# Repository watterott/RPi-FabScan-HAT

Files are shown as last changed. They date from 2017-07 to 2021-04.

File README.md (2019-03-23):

# RPi-FabScan-HAT
Raspberry Pi HAT (Hardware Attached on Top) to drive Stepper and Servo Motors or to build a 3D Laser Scanner.

Infos about the FabScan 3D-Scanner: http://www.fabscan.org

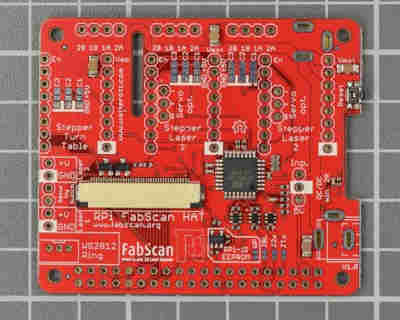
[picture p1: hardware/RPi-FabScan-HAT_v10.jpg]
RPi-FabScan-HAT


* Microchip ATmega328P with Arduino compatible Bootloader (optiboot)
* Sockets for Stepper Motor Drivers like StepStick or SilenStepStick
* Connectors for Servo Motors
* Laser control outputs
* [Raspberry Pi HAT](https://github.com/raspberrypi/hats) compatible (40 pin connector)
* Open-Source and released under the [Creative Commons Attribution Share-Alike License](https://creativecommons.org/licenses/by-sa/4.0/).
* **[Documentation on learn.watterott.com](https://learn.watterott.com)**

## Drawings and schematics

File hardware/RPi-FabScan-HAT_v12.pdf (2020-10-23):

## M1_EN

## M1_STEP

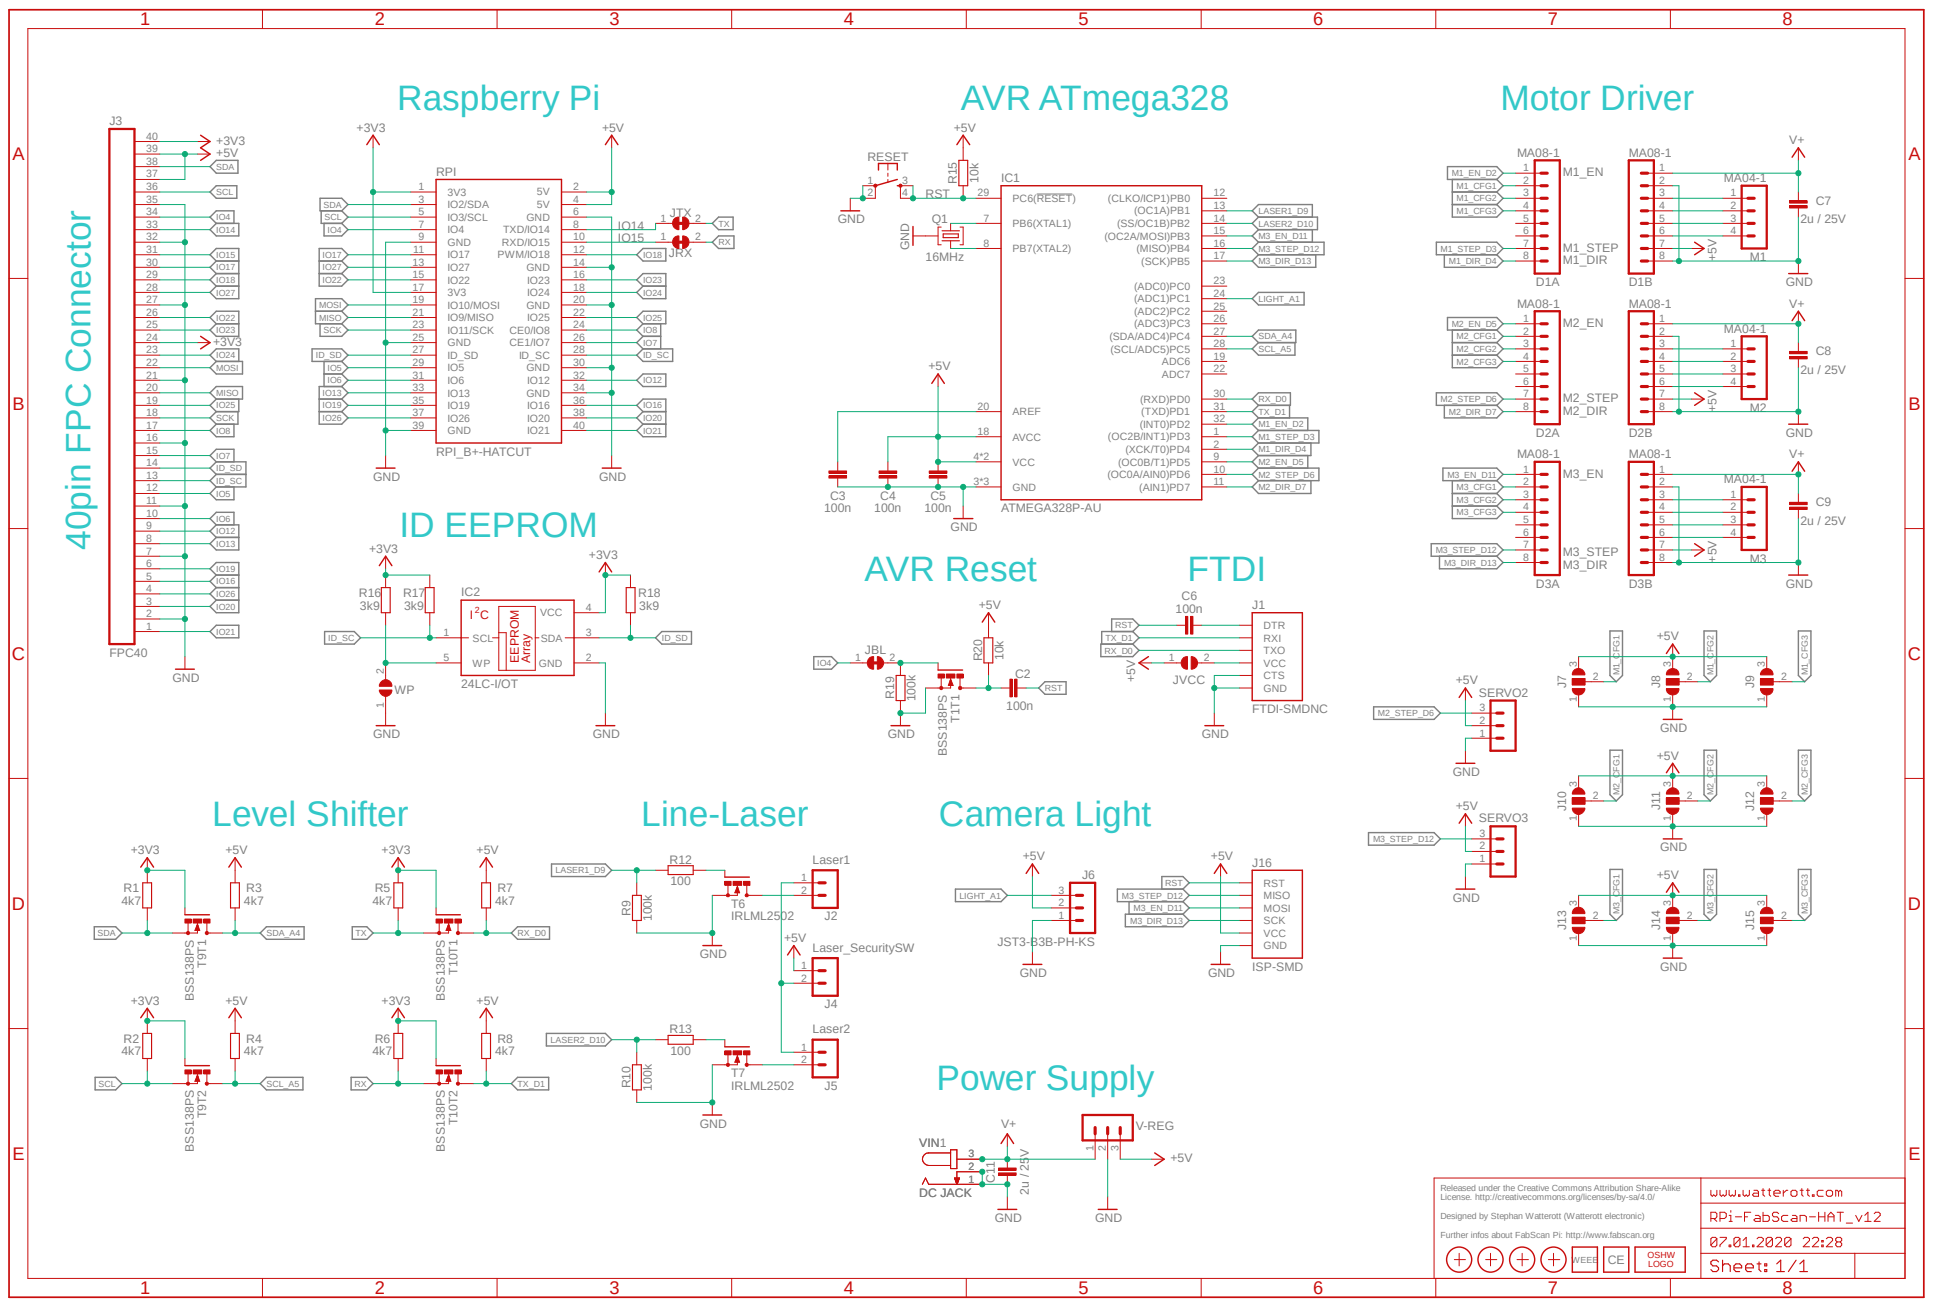
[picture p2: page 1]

M2_STEP_D6 +5V | 2

M3_STEP_D12 | 2

Released under the Creative Commons Attribution Share-Alike
License. http://creativecommons.org/licenses/by-sa/4.0/

Designed by Stephan Watterott (Watterott electronic)

Further infos about FabScan Pi: http://www.fabscan.org

# Vmot

# Vmot

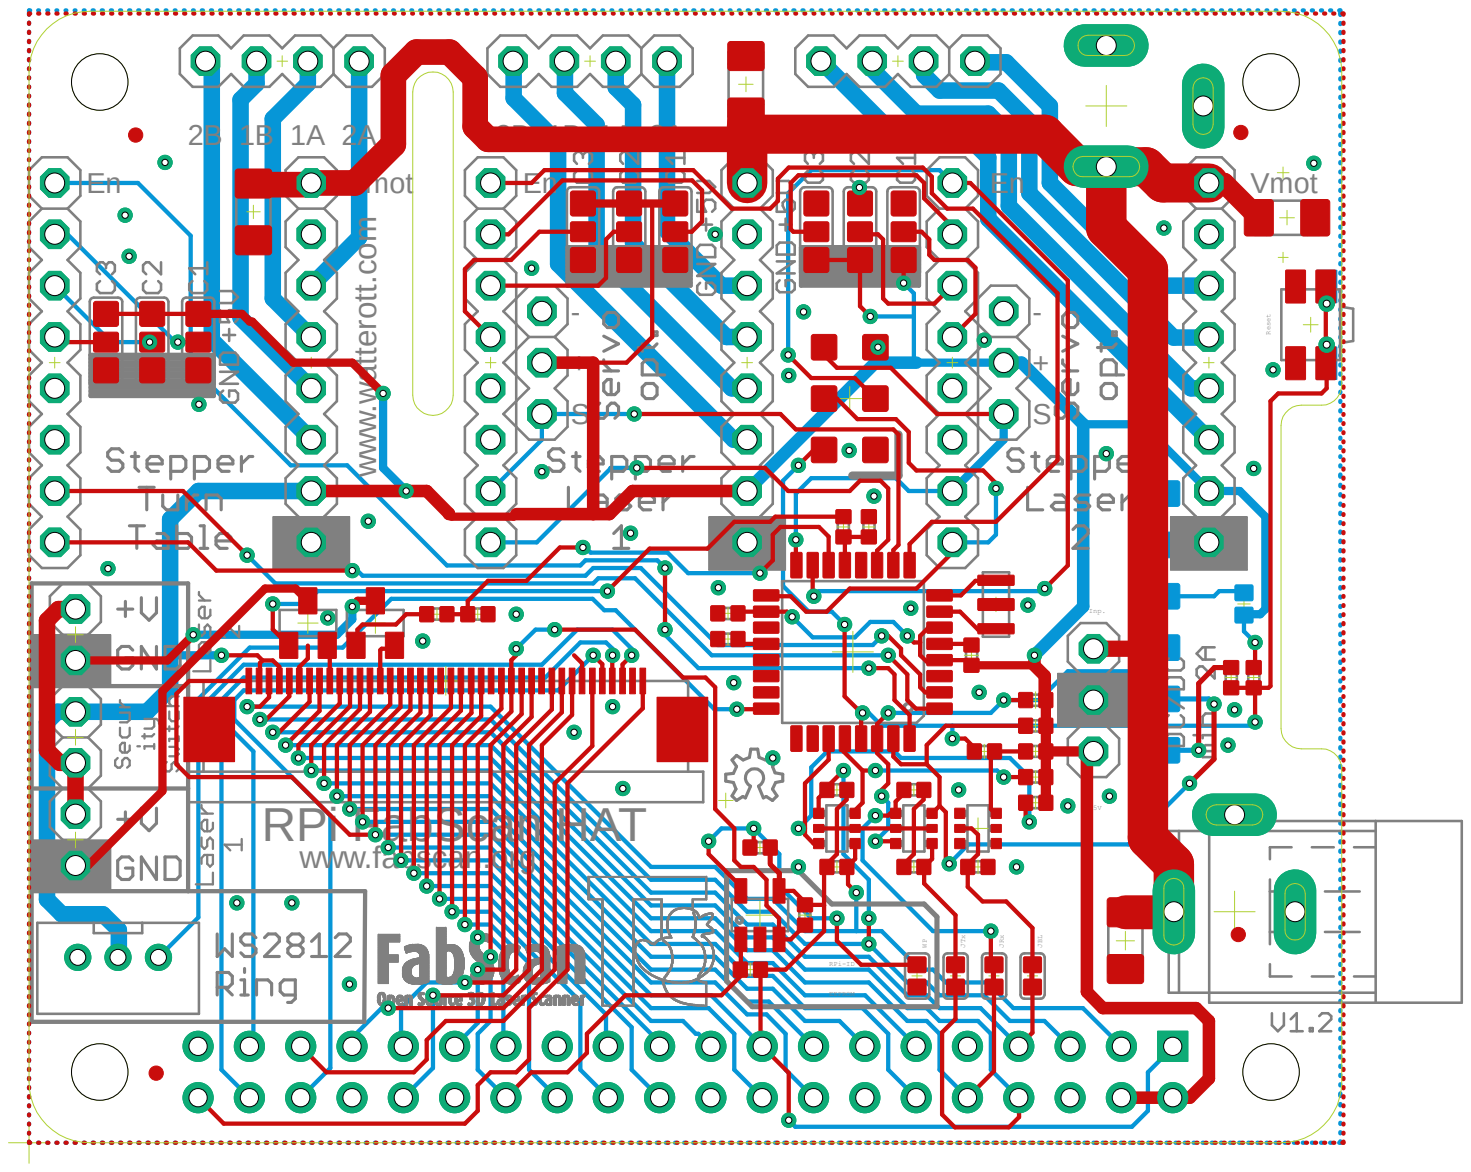
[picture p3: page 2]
Vmot -; 2B 1B 1A 2A www.watterott.com; Inp. WP; JTx; JRx; JBL; Reset; RPi-ID; EEPROM

RPi FabScan HAT
www.fabscan.org

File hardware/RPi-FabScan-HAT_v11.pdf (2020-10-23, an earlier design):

## M1_EN

## M1_STEP

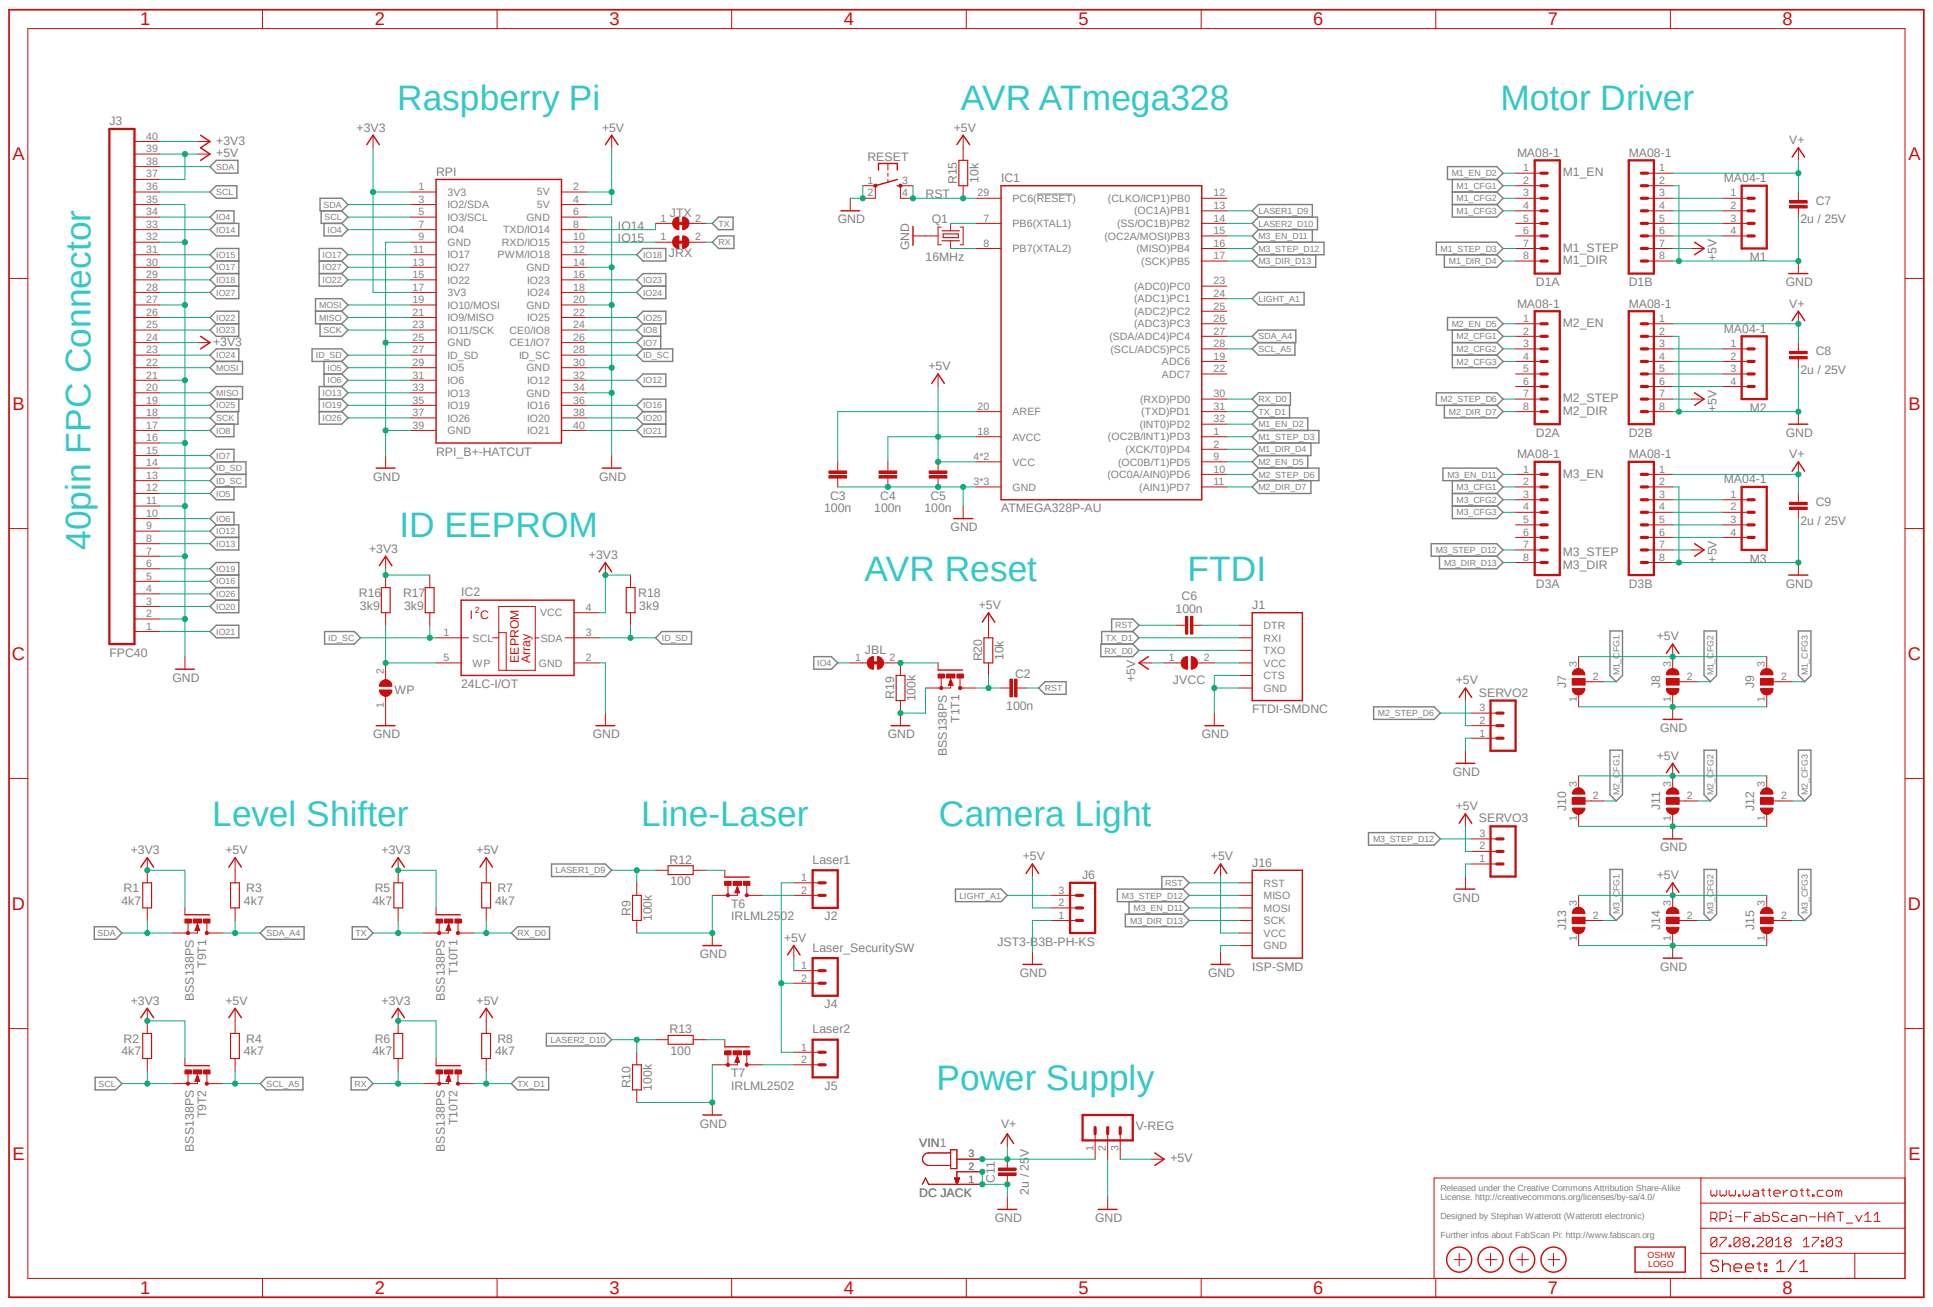
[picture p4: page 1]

M2_STEP_D6 +5V | 2

M3_STEP_D12 | 2

Released under the Creative Commons Attribution Share-Alike
License. http://creativecommons.org/licenses/by-sa/4.0/

Designed by Stephan Watterott (Watterott electronic)

Further infos about FabScan Pi: http://www.fabscan.org

# Vmot

# Vmot

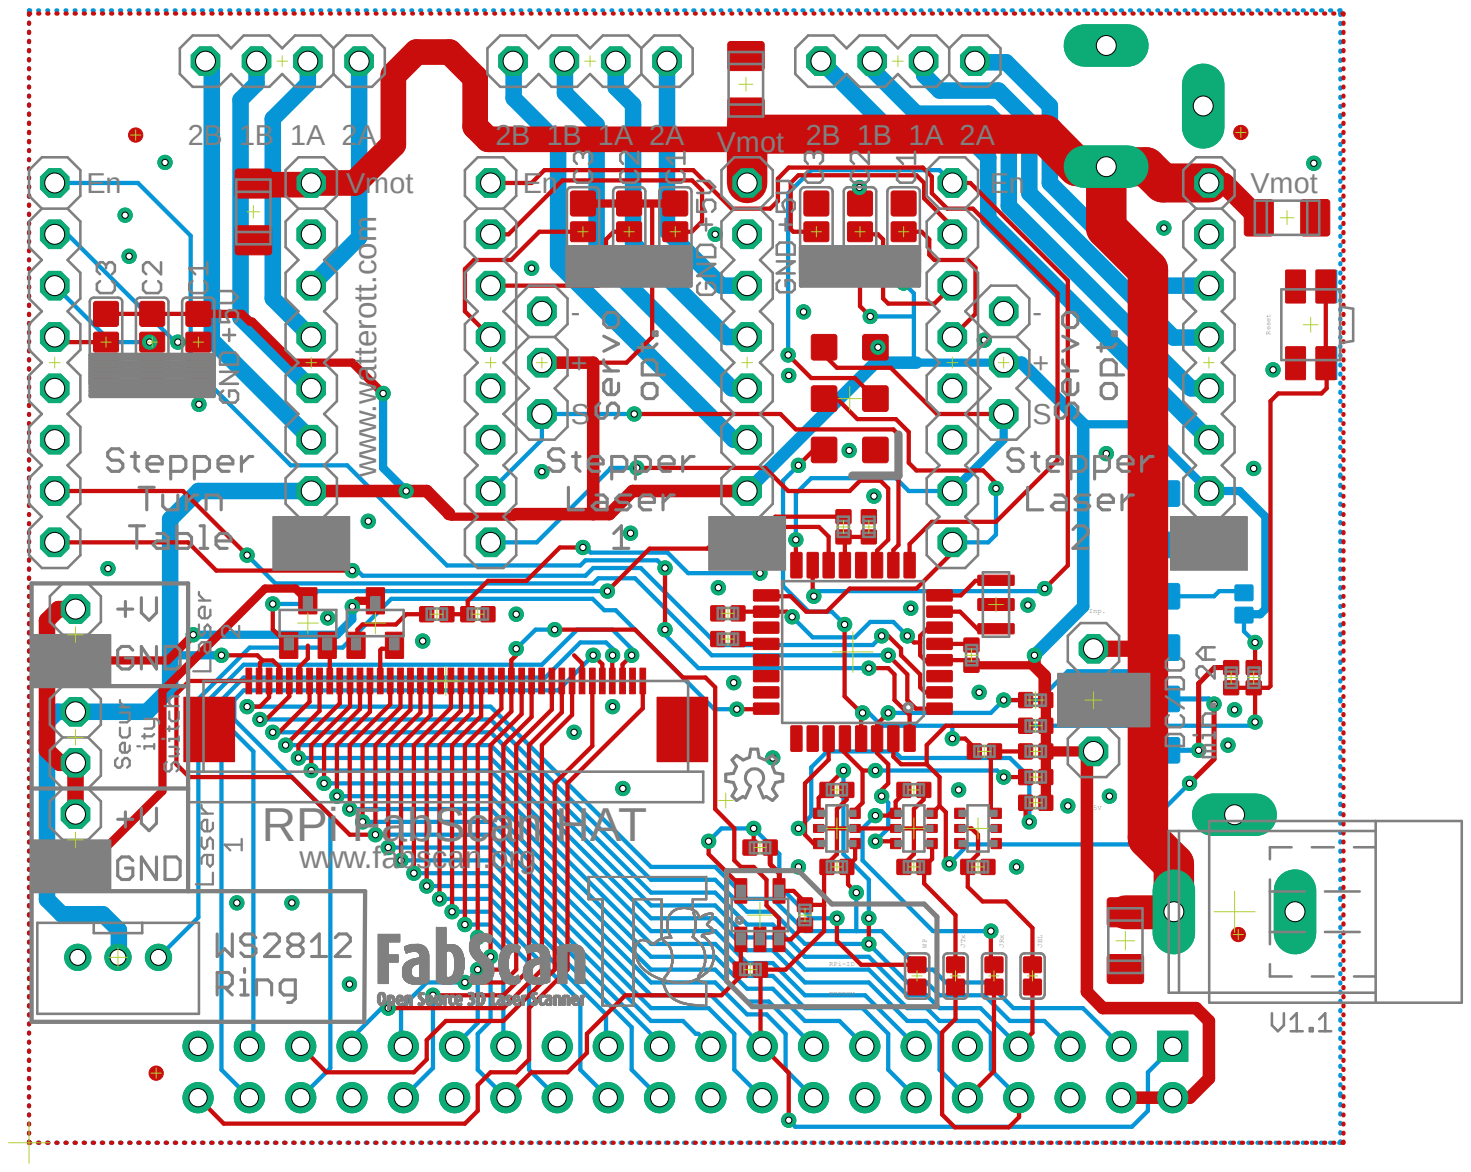
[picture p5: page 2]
Vmot -; 2B 1B 1A 2A www.watterott.com; Inp. WP; JTx; JRx; JBL; Reset; RPi-ID; EEPROM

RPi FabScan HAT
www.fabscan.org

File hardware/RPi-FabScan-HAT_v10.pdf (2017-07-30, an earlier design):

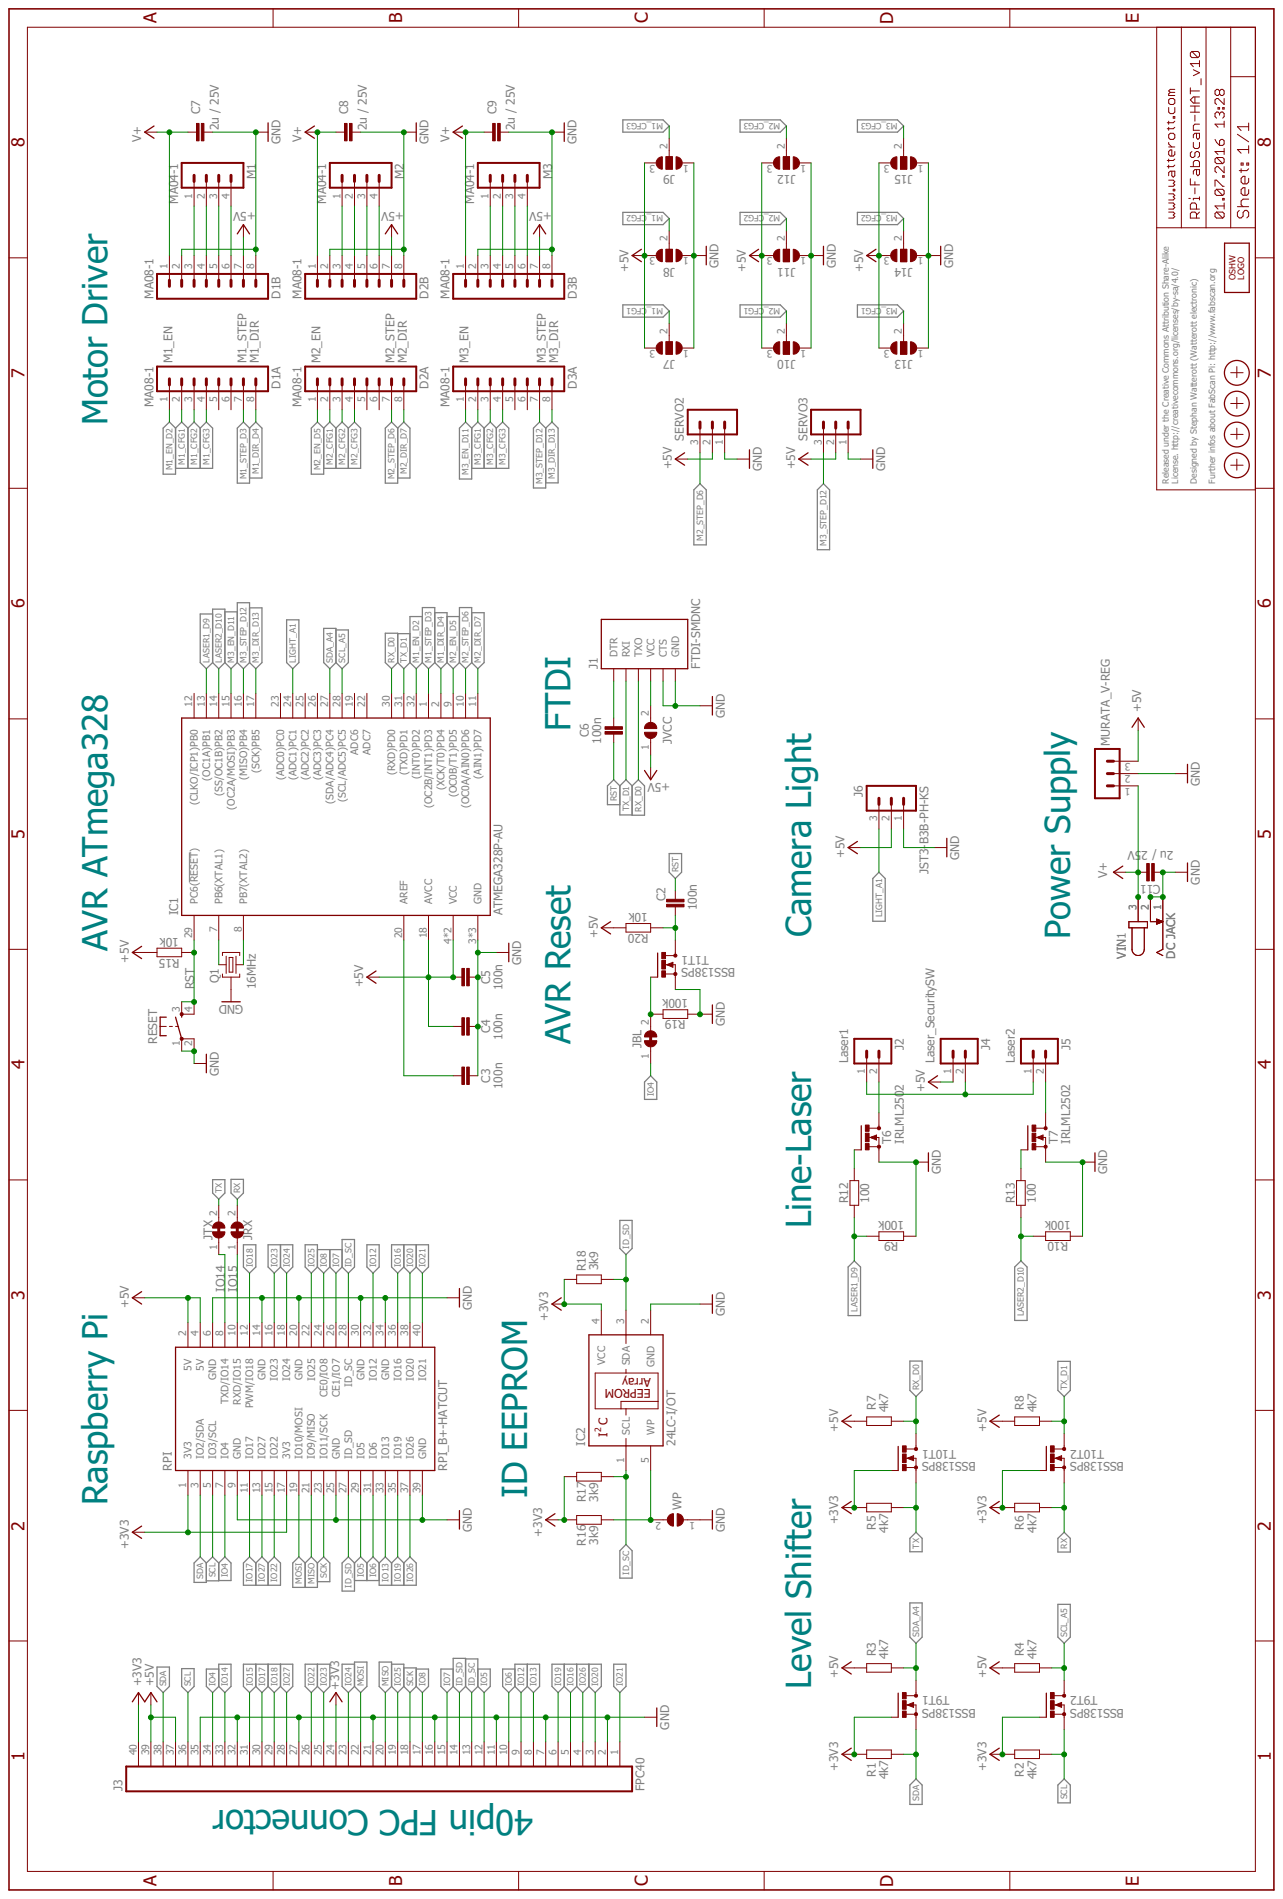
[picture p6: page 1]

Released under the Creative Commons Attribution Share-Alike

License. http://creativecommons.org/licenses/by-sa/4.0/ Designed by Stephan Watterott (Watterott electronic) Further infos about FabScan Pi: http://www.fabscan.org

MOSI MOSI MISO MISO

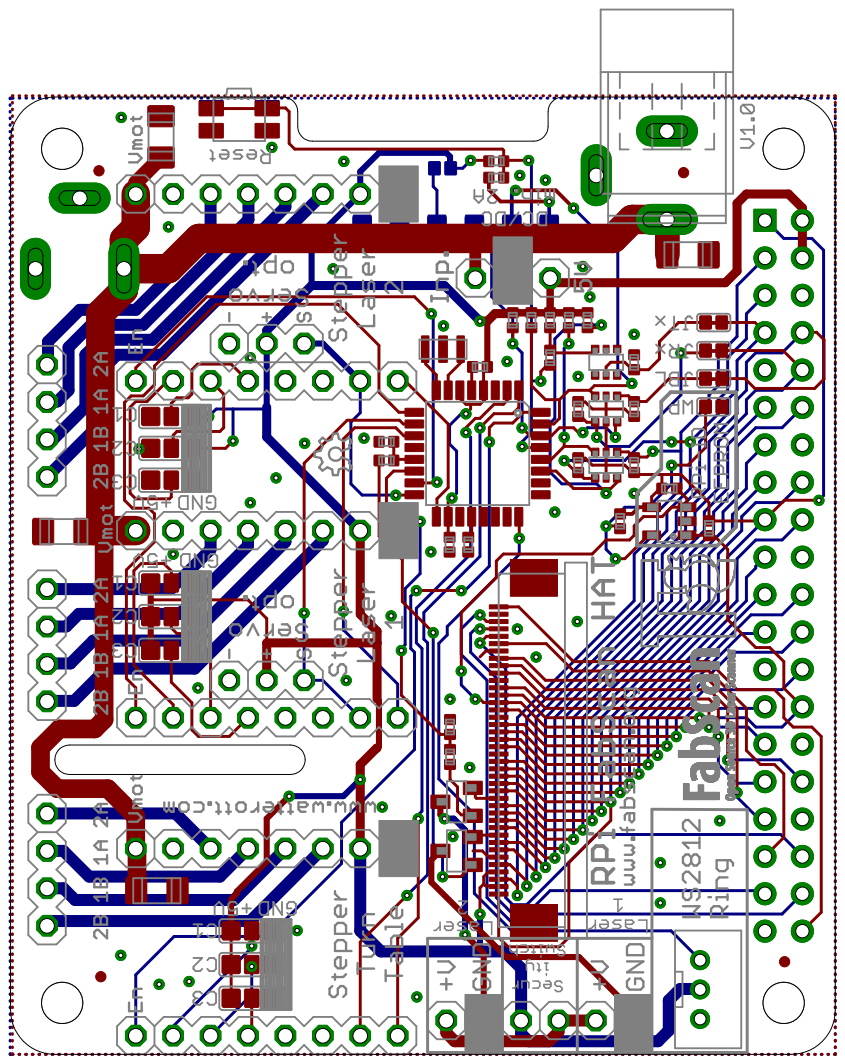
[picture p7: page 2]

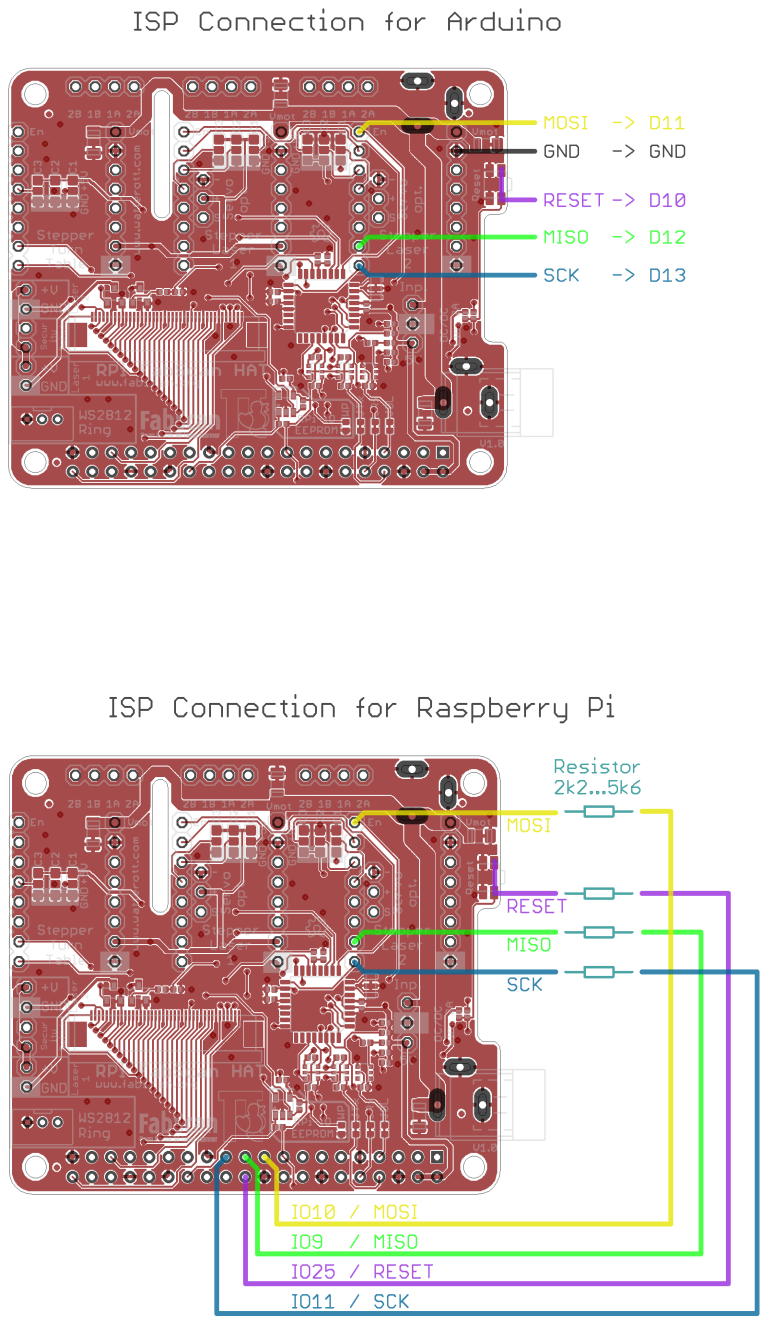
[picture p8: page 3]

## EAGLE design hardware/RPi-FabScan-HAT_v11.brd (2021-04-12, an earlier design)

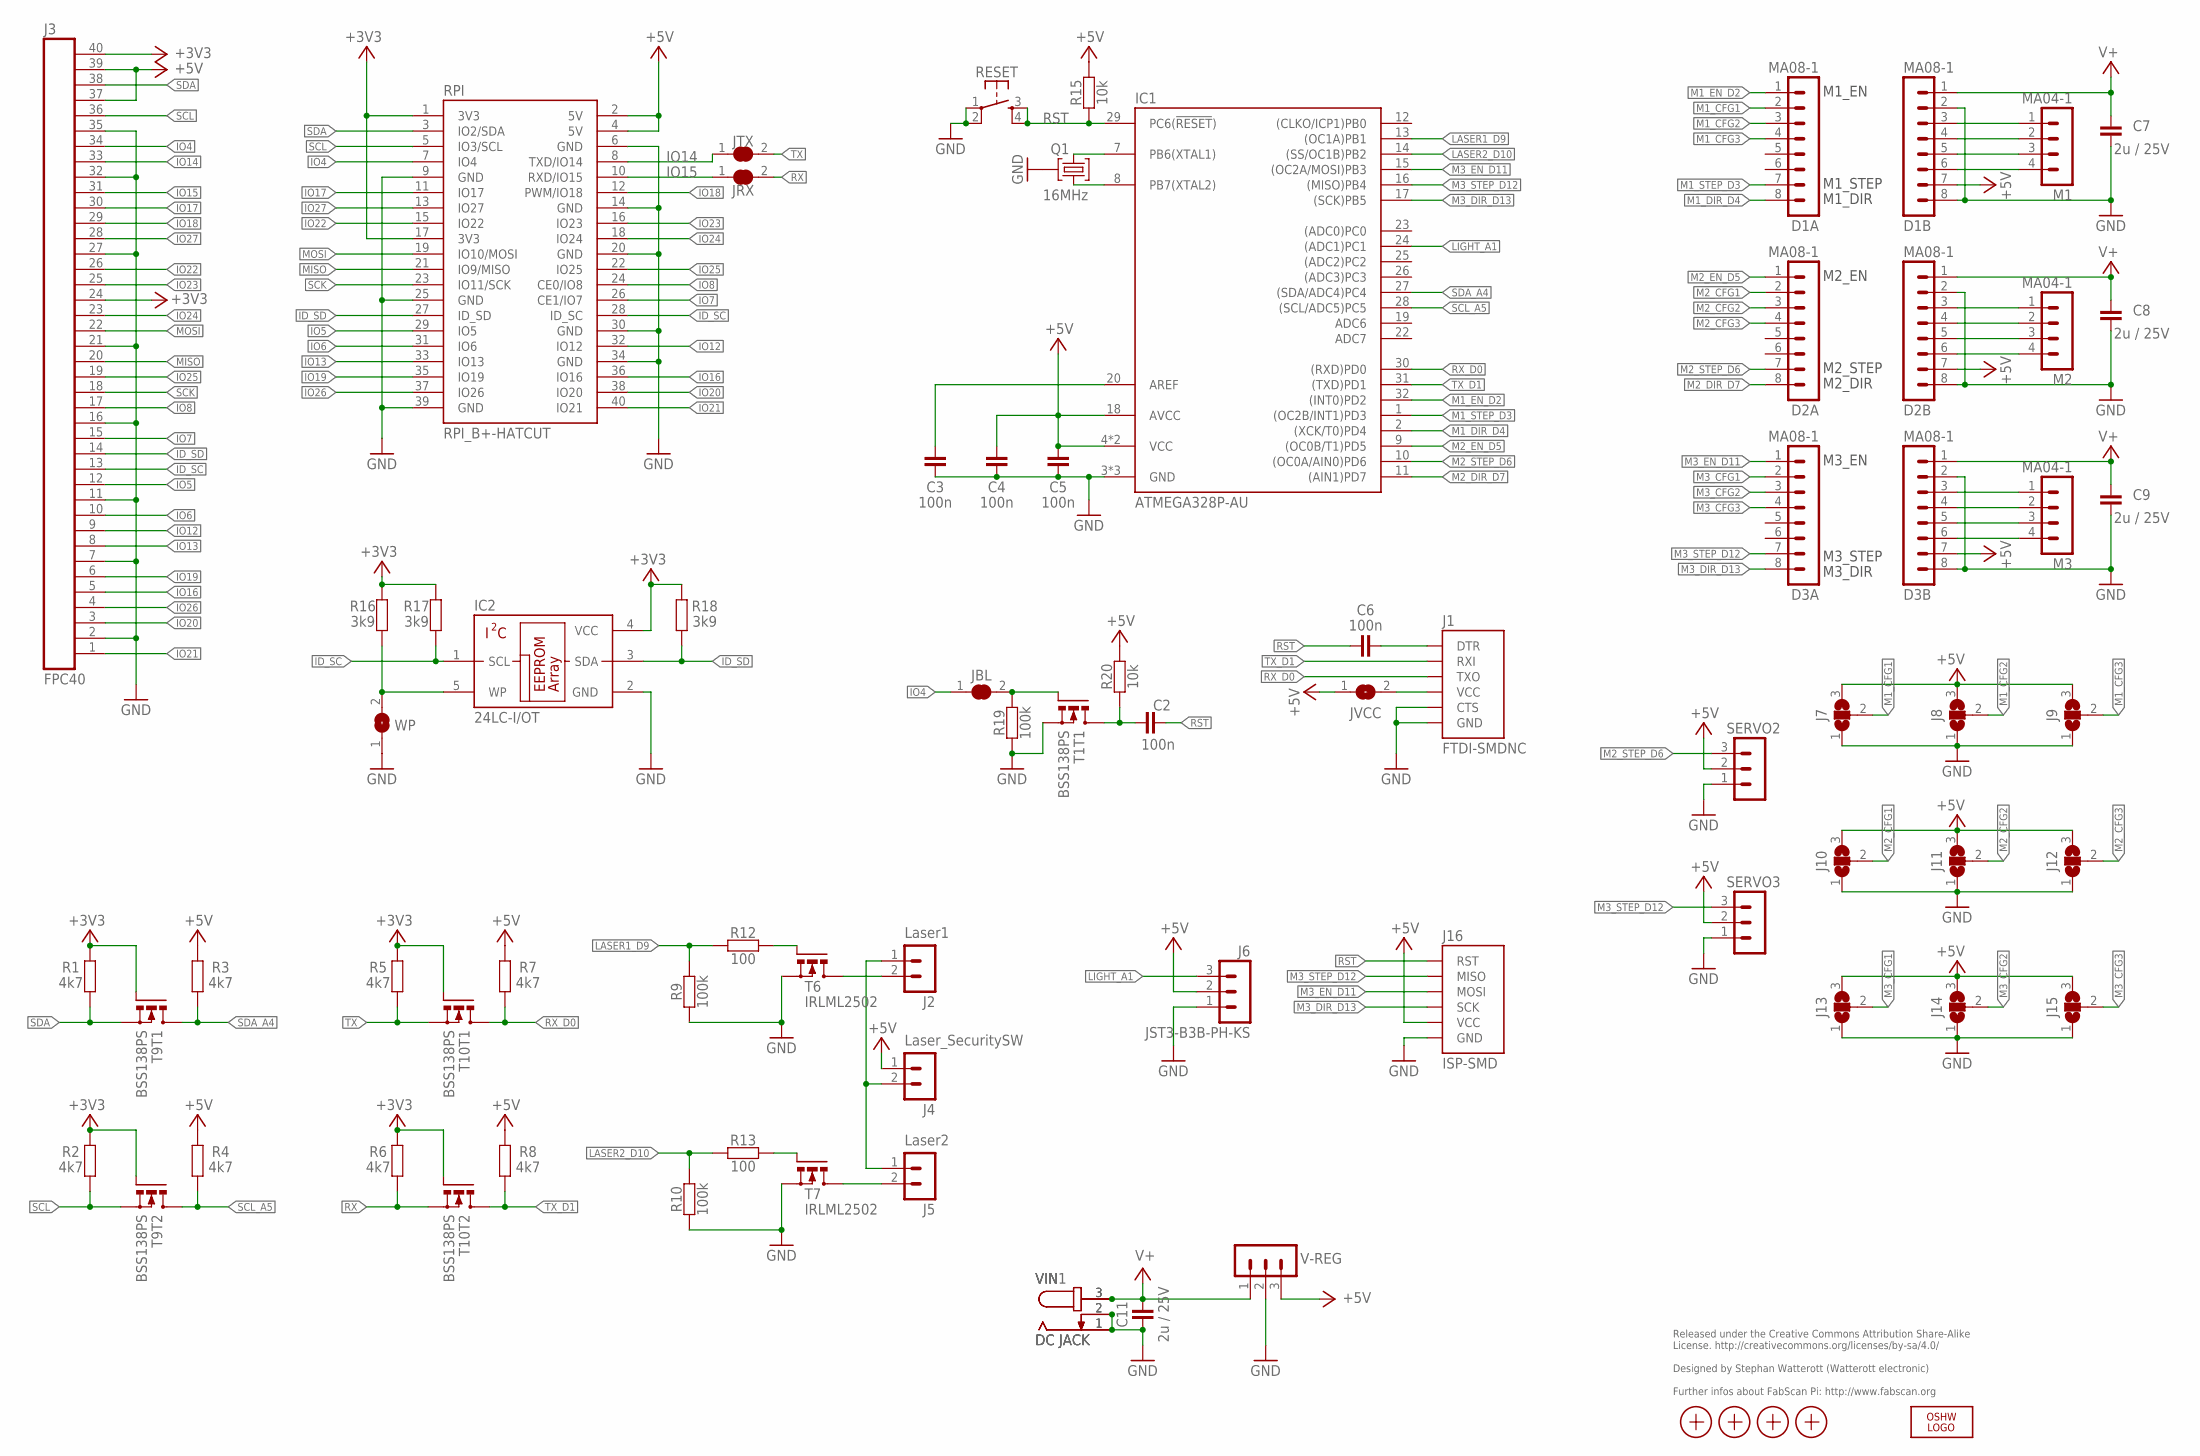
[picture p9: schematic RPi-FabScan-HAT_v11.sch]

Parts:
1, 2: PASSER-07; PASSER_07MM
C2, C3, C4, C5, C6: 100n; C0402
C7, C8, C9, C11: 2u / 25V; C1206
D1A, D1B, D2A, D2B, D3A, D3B: MA08-1
IC1: ATMEGA328P-AU; TQFP32
IC2: 24LC-I/OT; SOT23-5
J1: FTDI-SMDNC; FTDI_SMDNC
J2: Laser1; MA02-1
J3: FPC40; FPC40-0.5
J4: Laser_SecuritySW; MA02-1
J5: Laser2; MA02-1
J6: JST3-B3B-PH-KS; JST_B3B-PH-KS
J7, J8, J9, J10, J11, J12, J13, J14, J15: JUMPER3-0603-NC; JUMPER3-0603_NC
J16: ISP-SMD; ISP-2X3_SMD
JBL: JUMPER2-0402-NC; JUMPER2-0402_NC
JRX: JUMPER2-0402-NC; JUMPER2-0402_NC
JTX: JUMPER2-0402-NC; JUMPER2-0402_NC
JVCC: JUMPER2-0402-NC; JUMPER2-0402_NC
LOGO2: OSHW_LOGOX0100; OSHW_6X100
M1, M2, M3: MA04-1
Q1: 16MHz; CRYSTAL_32X13
R1, R2, R3, R4, R5, R6, R7, R8: 4k7; C0402
R9, R10, R19: 100k; C0402
R12, R13: 100; C0402
R15, R20: 10k; C0402
R16, R17, R18: 3k9; C0402
RESET: SW-TACTILE-PTS840P; SW_PTS840P
RPI: RPI_B+-HATCUT; RPI-B+HAT_CUTOUT
SERVO2, SERVO3: MA03-1
T1, T9, T10: BSS138PS; SOT363
T6, T7: IRLML2502; SOT23
V-REG: MA03-1
VIN, VIN1: DC JACK; DC-JACK
WP: JUMPER2-0402-NC; JUMPER2-0402_NC
X1, X4: PASSER-07; PASSER_07MM

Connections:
+3V3: IC2.4 (VCC), J3.24, J3.40, R1.1, R2.1, R5.1, R6.1, R16.2, R17.2, R18.2, RPI.1 (3V3), RPI.17 (3V3), T9.2 (G), T9.5 (G), T10.2 (G), T10.5 (G)
+5V: C4.2, C5.2, D1B.7, D2B.7, D3B.7, IC1.4 (VCC), IC1.6 (VCC), IC1.18 (AVCC), J3.37, J3.39, J4.1, J6.2, J7.3, J8.3, J9.3, J10.3, J11.3, J12.3, J13.3, J14.3, J15.3, J16.VCC, JVCC.1, R3.1, R4.1, R7.1, R8.1, R15.2, R20.2, RPI.2 (5V), RPI.4 (5V), SERVO2.2, SERVO3.2, V-REG.3
GND: C3.1, C4.1, C5.1, C7.1, C8.1, C9.1, C11.1, D1B.2, D1B.8, D2B.2, D2B.8, D3B.2, D3B.8, IC1.3 (GND), IC1.5 (GND), IC1.21 (GND), IC2.2 (GND), J1.1-GND (GND), J1.2-CTS (CTS), J3.2, J3.7, J3.11, J3.16, J3.21, J3.27, J3.32, J3.35, J6.1, J7.1, J8.1, J9.1, J10.1, J11.1, J12.1, J13.1, J14.1, J15.1, J16.GND, Q1.GND, R9.1, R10.1, R19.1, RESET.1, RESET.2, RPI.6 (GND), RPI.9 (GND), RPI.14 (GND), RPI.20 (GND), RPI.25 (GND), RPI.30 (GND), RPI.34 (GND), RPI.39 (GND), SERVO2.1, SERVO3.1, T1.1 (S), T6.2 (S), T7.2 (S), V-REG.2, VIN.1, VIN.2, VIN1.1, VIN1.2, WP.1
ID_SC: IC2.1 (SCL), J3.13, R17.1, RPI.28 (ID_SC)
ID_SD: IC2.3 (SDA), J3.14, R18.1, RPI.27 (ID_SD)
IO4: J3.34, JBL.1, RPI.7 (IO4)
IO5: J3.12, RPI.29 (IO5)
IO6: J3.10, RPI.31 (IO6)
IO7: J3.15, RPI.26 (CE1/IO7)
IO8: J3.17, RPI.24 (CE0/IO8)
IO12: J3.9, RPI.32 (IO12)
IO13: J3.8, RPI.33 (IO13)
IO14: J3.33, JTX.1, RPI.8 (TXD/IO14)
IO15: J3.31, JRX.1, RPI.10 (RXD/IO15)
IO16: J3.5, RPI.36 (IO16)
IO17: J3.30, RPI.11 (IO17)
IO18: J3.29, RPI.12 (PWM/IO18)
IO19: J3.6, RPI.35 (IO19)
IO20: J3.3, RPI.38 (IO20)
IO21: J3.1, RPI.40 (IO21)
IO22: J3.26, RPI.15 (IO22)
IO23: J3.25, RPI.16 (IO23)
IO24: J3.23, RPI.18 (IO24)
IO25: J3.19, RPI.22 (IO25)
IO26: J3.4, RPI.37 (IO26)
IO27: J3.28, RPI.13 (IO27)
LASER1_D9: IC1.13 ((OC1A)PB1), R9.2, R12.1
LASER2_D10: IC1.14 ((SS/OC1B)PB2), R10.2, R13.1
LIGHT_A1: IC1.24 ((ADC1)PC1), J6.3
M1_CFG1: D1A.2, J7.2
M1_CFG2: D1A.3, J8.2
M1_CFG3: D1A.4, J9.2
M1_DIR_D4: D1A.8, IC1.2 ((XCK/T0)PD4)
M1_EN_D2: D1A.1, IC1.32 ((INT0)PD2)
M1_STEP_D3: D1A.7, IC1.1 ((OC2B/INT1)PD3)
M2_CFG1: D2A.2, J10.2
M2_CFG2: D2A.3, J11.2
M2_CFG3: D2A.4, J12.2
M2_DIR_D7: D2A.8, IC1.11 ((AIN1)PD7)
M2_EN_D5: D2A.1, IC1.9 ((OC0B/T1)PD5)
M2_STEP_D6: D2A.7, IC1.10 ((OC0A/AIN0)PD6), SERVO2.3
M3_CFG1: D3A.2, J13.2
M3_CFG2: D3A.3, J14.2
M3_CFG3: D3A.4, J15.2
M3_DIR_D13: D3A.8, IC1.17 ((SCK)PB5), J16.SCK
M3_EN_D11: D3A.1, IC1.15 ((OC2A/MOSI)PB3), J16.MOSI
M3_STEP_D12: D3A.7, IC1.16 ((MISO)PB4), J16.MISO, SERVO3.3
MISO: J3.20, RPI.21 (IO9/MISO)
MOSI: J3.22, RPI.19 (IO10/MOSI)
unnamed: IC1.7 (PB6(XTAL1)), Q1.2
unnamed: IC1.8 (PB7(XTAL2)), Q1.1
unnamed: D3B.3, M3.1
unnamed: C3.2, IC1.20 (AREF)
unnamed: R12.2, T6.1 (G)
unnamed: R13.2, T7.1 (G)
unnamed: C6.1, J1.6-DTR (DTR)
unnamed: J2.1, J4.2, J5.1
unnamed: JBL.2, R19.2, T1.2 (G)
unnamed: C2.2, R20.1, T1.6 (D)
unnamed: J2.2, T6.3 (D)
unnamed: D3B.4, M3.2
unnamed: D3B.5, M3.3
unnamed: D3B.6, M3.4
unnamed: D2B.3, M2.1
unnamed: D2B.4, M2.2
unnamed: D2B.5, M2.3
unnamed: D2B.6, M2.4
unnamed: D1B.3, M1.1
unnamed: D1B.4, M1.2
unnamed: D1B.5, M1.3
unnamed: D1B.6, M1.4
unnamed: J5.2, T7.3 (D)
unnamed: IC2.5 (WP), R16.1, WP.2
RST: C2.1, C6.2, IC1.29 (PC6(!RESET!)), J16.RST, R15.1, RESET.3 (S1), RESET.4 (S2)
RX: JRX.2, R6.2, T10.4 (S)
RX_D0: IC1.30 ((RXD)PD0), J1.4-TXO (TXO), R7.2, T10.6 (D)
SCK: J3.18, RPI.23 (IO11/SCK)
SCL: J3.36, R2.2, RPI.5 (IO3/SCL), T9.4 (S)
SCL_A5: IC1.28 ((SCL/ADC5)PC5), R4.2, T9.3 (D)
SDA: J3.38, R1.2, RPI.3 (IO2/SDA), T9.1 (S)
SDA_A4: IC1.27 ((SDA/ADC4)PC4), R3.2, T9.6 (D)
TX: JTX.2, R5.2, T10.1 (S)
TX_D1: IC1.31 ((TXD)PD1), J1.5-RXI (RXI), R8.2, T10.3 (D)
V+: C7.2, C8.2, C9.2, C11.2, D1B.1, D2B.1, D3B.1, V-REG.1, VIN.3, VIN1.3
VCC_FTDI: J1.3-VCC (VCC), JVCC.2

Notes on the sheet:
M1_EN
M1_STEP
M1_DIR
M2_EN
M2_STEP
M2_DIR
M3_EN
M3_STEP
M3_DIR
Released under the Creative Commons Attribution Share-Alike License. http://creativecommons.org/licenses/by-sa/4.0/ Designed by Stephan Watterott (Watterott electronic) Further infos about FabScan Pi: http://www.fabscan.org

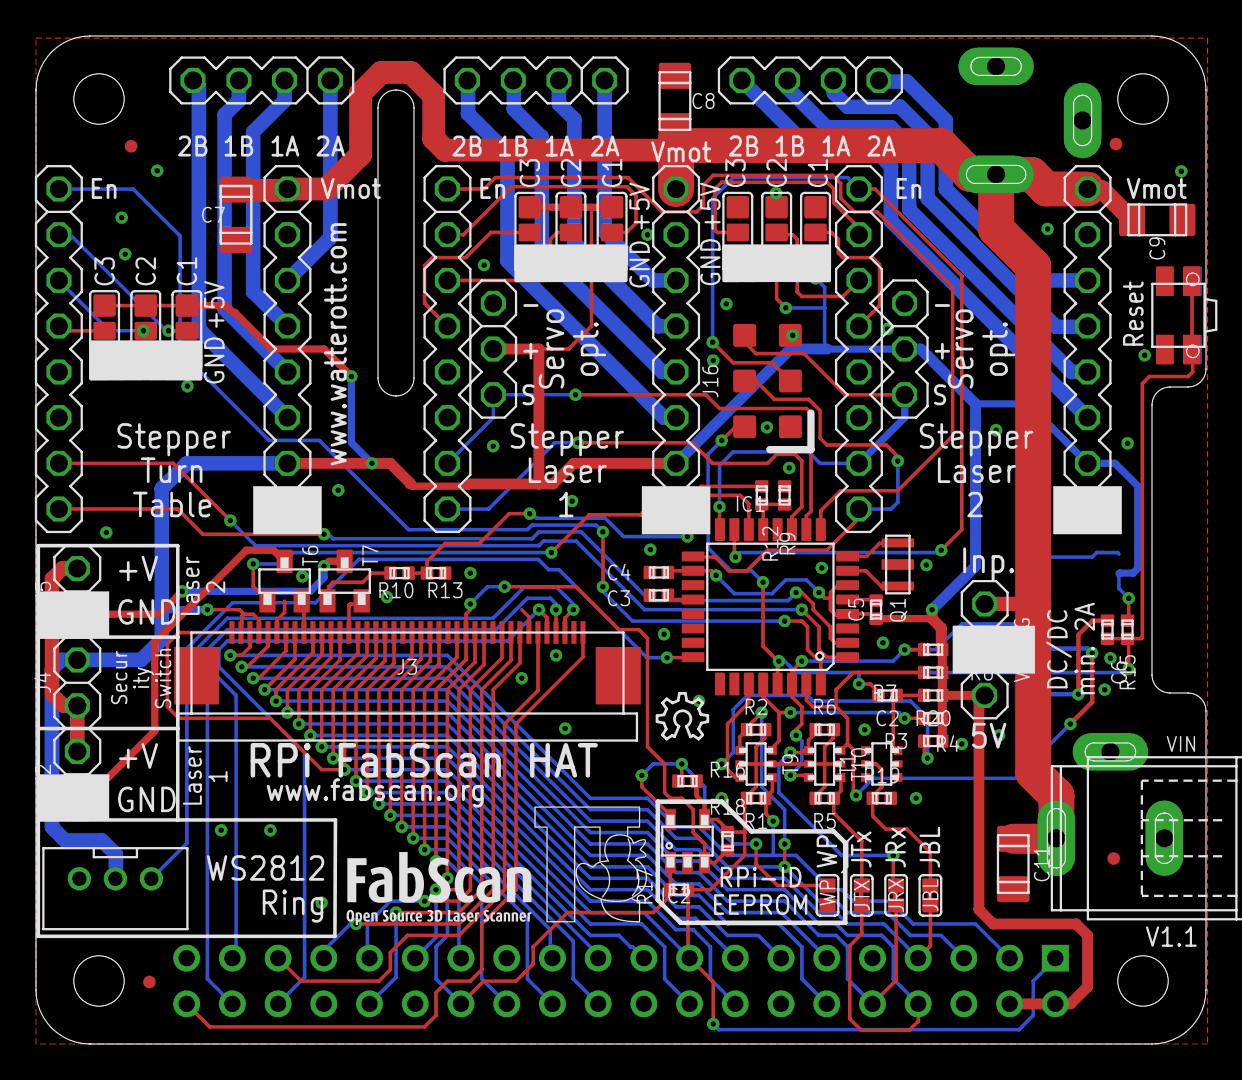
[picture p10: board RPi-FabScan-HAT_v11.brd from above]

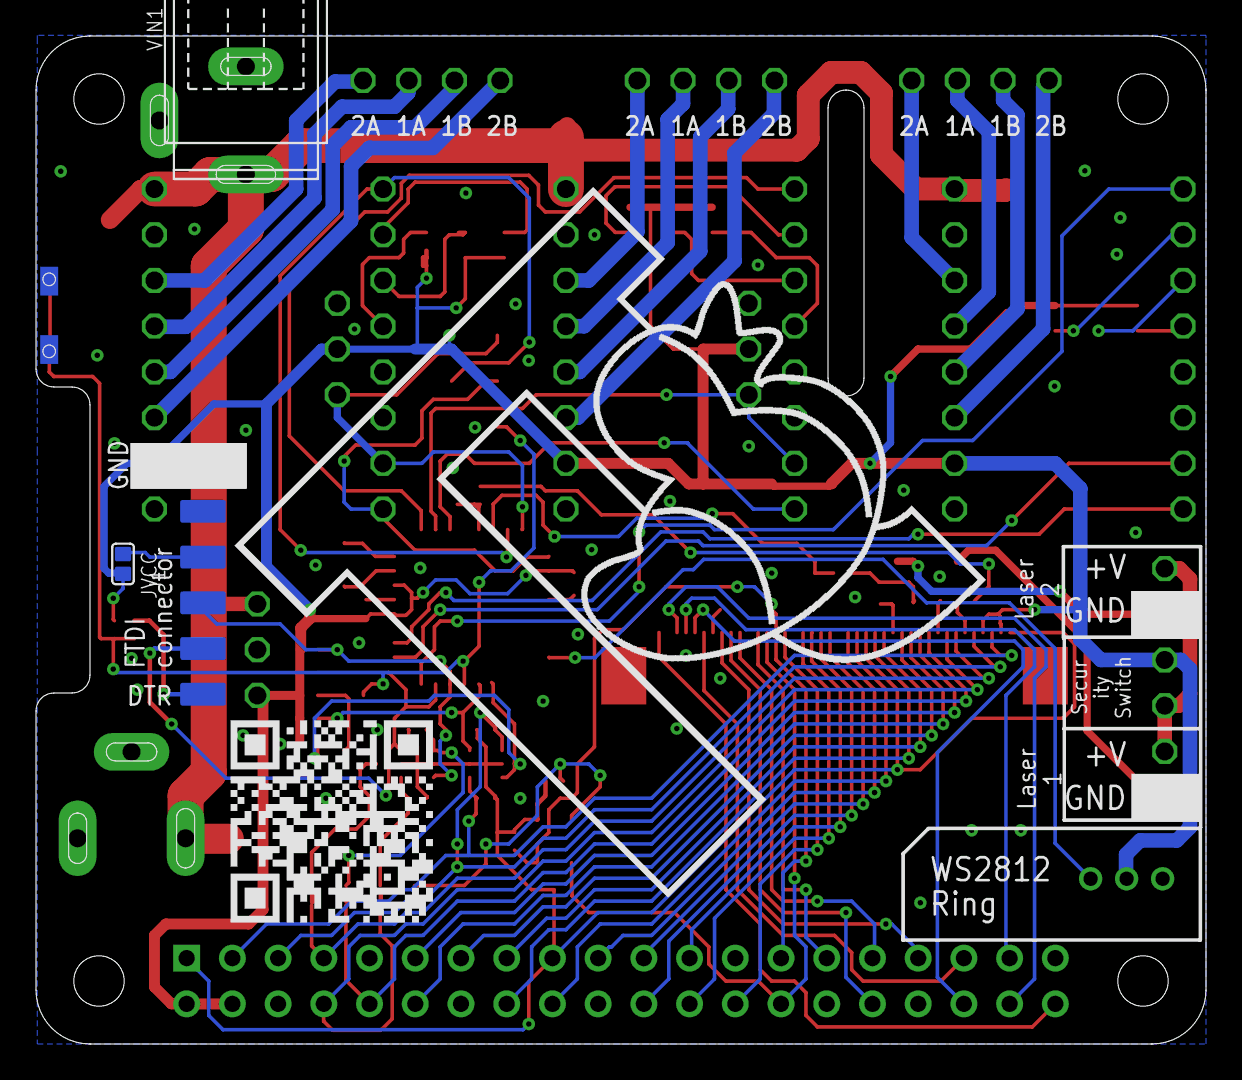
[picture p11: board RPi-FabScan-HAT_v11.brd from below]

Board: 2 copper layers, 65.0 x 56.0 mm, 77 parts (3 on the bottom side), 85 nets.

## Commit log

2020-10-23 added V1.1
    [RPi-FabScan-HAT_v11.brd, RPi-FabScan-HAT_v11.sch]
2020-10-23 added V1.2
    [RPi-FabScan-HAT_v12.brd, RPi-FabScan-HAT_v12.sch]
2021-04-12 convert to Eagle 7
    [RPi-FabScan-HAT_v11.brd, RPi-FabScan-HAT_v11.sch, RPi-FabScan-HAT_v12.brd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]
